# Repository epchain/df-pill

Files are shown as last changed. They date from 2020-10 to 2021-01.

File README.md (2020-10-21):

# df-pill

This project was extracted from another, complex device project which originally
targeted cheap STM32F103C8T6 board known as "bluepill" as main board.
However, it soon became apparent that bluepill has shortcomings with USB
interface, which was meant to be primary communication channel.

**tl;dr** bluepill cannot work with USB while being externally powered.
It is designed to be powered with USB host only.
Some bluepill boards have hardware bugs.

To overcome problems this board was designed.
It has a number of enhancements and was thought to be maximally generic.

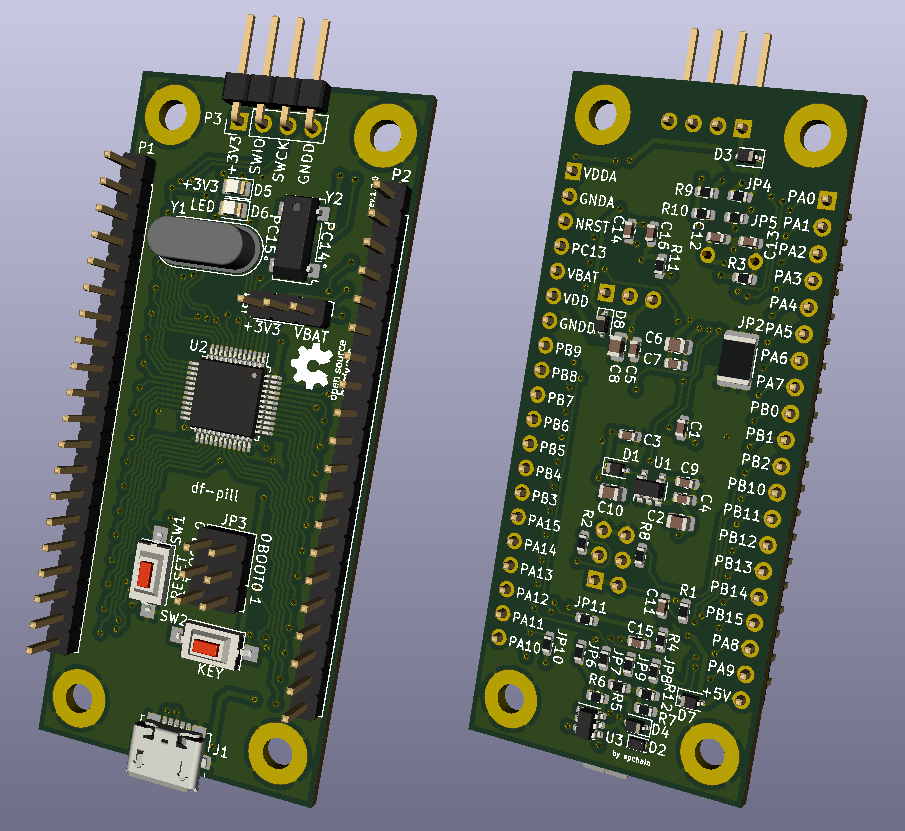
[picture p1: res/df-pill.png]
df-pill


**Enhancements:**

1. Improved USB
  > USB now has optional ESD protection, implements VBUS sense with software
  > and is fully detachable via jumpers.

2. Every pin has external connection
  > NOTE: some pins like PC14, PC15, BOOT0 don't have terminals at the board
  > sides, but still have them at crystal mount points and boot pin headers.

3. Separate analog terminals VDDA and GNDA and separate analog ground
  > NOTE: It is required to provide VDDA and GNDA or simply join them
  > with VDD and GNDD. GNDA and GNDD may be joined on board with jumper.
  > VDD and VDDA may be joined via terminals.

4. Detachable add-ons
  > On-board LEDs and keys can be detached with jumpers.

5. VDD and +5V inputs are protected power inputs.
  > All power supply nets are now protected with Schottky diodes.

The goal of this project is to learn electronics while creating a useful device,
for everyone. So keep in mind that this device isn't designed by professional.

It is assumed that user is able to perform all necessary tasks related to
device creation, which are not covered with project files. User must also
perform all necessary precautions on every such task. See [LICENSE](LICENSE).

This means things like electrical safety, soldering, parts ordering and
PCB manufacturing are out of the scope. As a note, if you think you can
buy bluepill, disassemble it and apply its parts to this board, then
you're right. Bluepill has core parts, but some other uncommon ones need
to be ordered.

# How to use

Install Kicad EDA and open project file: `device/df-pill/df-pill.pro`.
Original project was made with *Kicad EDA 5.1.5-3*

You don't need any library installed, because project is fully autonomous.
It has all symbols, footprints and 3D models in `device/df-pill/lib` dir.

If you like to change anything it is recommended to first add new items
to library and then use them in project to maintain autonomous project
structure.

If you'd like to have multiple boards on a single copper plate
read `device/panelization.md`.

# Versioning

Schematic and and PCB have different, but related version formats.

- Schematic: **X.Y**
- PCB: **X.Y.Z**

Where **X** = major version, **Y** = minor version, **Z** = patch.

Schematic major version increment breaks external interface.
Minor version increment changes components, but external interface
is the same. Any schematic version change breaks PCB layout.

PCB's major and minor versions are from schematic versions.
Patches are PCB modifications/optimizations that are fully
compatible with current schematic.

# References

A number of resources was used in this project.
See [reference.md](reference.md) for list.

# License

This project is licensed under [The Unlicense](LICENSE).
It contains library files from KiCAD EDA library in `device/lib`.
These files are licensed under [KiCAD EDA Libraries License](https://kicad-pcb.org/libraries/license/)

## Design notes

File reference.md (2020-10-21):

# Reference

There you can find a list of all documents used in this project,
given in order from general to more specific.

### USB:

1. [USB 2.0 Specification](https://www.usb.org/sites/default/files/usb_20_20190524.zip)
2. [Mass Storage Class Specification Overview 1.4](https://www.usb.org/sites/default/files/Mass_Storage_Specification_Overview_v1.4_2-19-2010.pdf)
3. [Mass Storage Bulk Only 1.0](https://www.usb.org/sites/default/files/usbmassbulk_10.pdf)
4. [SCSI Primary Commands - 3 (SPC-3)](https://www.t10.org/cgi-bin/ac.pl?t=f&f=spc3r23.pdf)
5. [SCSI Block Commands - 2 (SBC-2)](https://www.t10.org/cgi-bin/ac.pl?t=f&f=sbc2r16.pdf)

### ST:

1. [STM32F103x8-xB Datasheet](https://www.st.com/resource/en/datasheet/stm32f103c8.pdf)
2. [STM32F10xxx Reference manual (RM0008)](https://www.st.com/resource/en/reference_manual/cd00171190.pdf)
4. [Getting started with STM32F10xxx hardware development
 (AN2586)](https://www.st.com/resource/en/application_note/cd00164185.pdf)
5. [Oscillator design guide for STM8AF-AL-S, STM32 MCUs and MPUs (AN2867)](https://www.st.com/resource/en/application_note/cd00221665.pdf)
6. [STM32 GPIO configuration for hardware settings 
and low-power consumption](https://www.st.com/resource/en/application_note/dm00315319.pdf)
7. [USB hardware and PCB guidelines using STM32 MCUs (AN4879)](https://www.st.com/resource/en/application_note/dm00296349.pdf)
8. [Monitoring the VBUS signal for USB self-powered devices (AN1040)](https://www.st.com/resource/en/application_note/cd00004193.pdf)
9. [Management of VBUS sensing for USB device design](https://community.st.com/s/article/FAQ-Management-of-VBUS-sensing-for-USB-device-design)

### Bluepill:

1. [Description from stm32-base.org](https://stm32-base.org/boards/STM32F103C8T6-Blue-Pill)
2. [Schematic](https://developer.mbed.org/media/uploads/martin159/stm32_min_system_dev_board.pdf)
3. [Pinout diagram](http://reblag.dk/wordpress/wp-content/uploads/2016/07/The-Generic-STM32F103-Pinout-Diagram.pdf)

### PCB:

1. [Staying Well Grounded, Hank Zumbahlen](https://www.analog.com/media/en/analog-dialogue/volume-46/number-2/articles/staying_well_grounded.pdf)

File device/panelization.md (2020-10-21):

# Panelization

To reduce manufacturing costs it is possible to create a separate `kicad_pcb`
file and place multiple PCB layouts on a single copper plate.

To do this open KiCad EDA's Pcbnew in standalone mode: launch `pcbnew` binary
instead of opening project with `kicad` binary.

Pcbnew will have `Append Board` option, unavailable in "kicad mode".
You may now append multiple layouts and place them as you like.

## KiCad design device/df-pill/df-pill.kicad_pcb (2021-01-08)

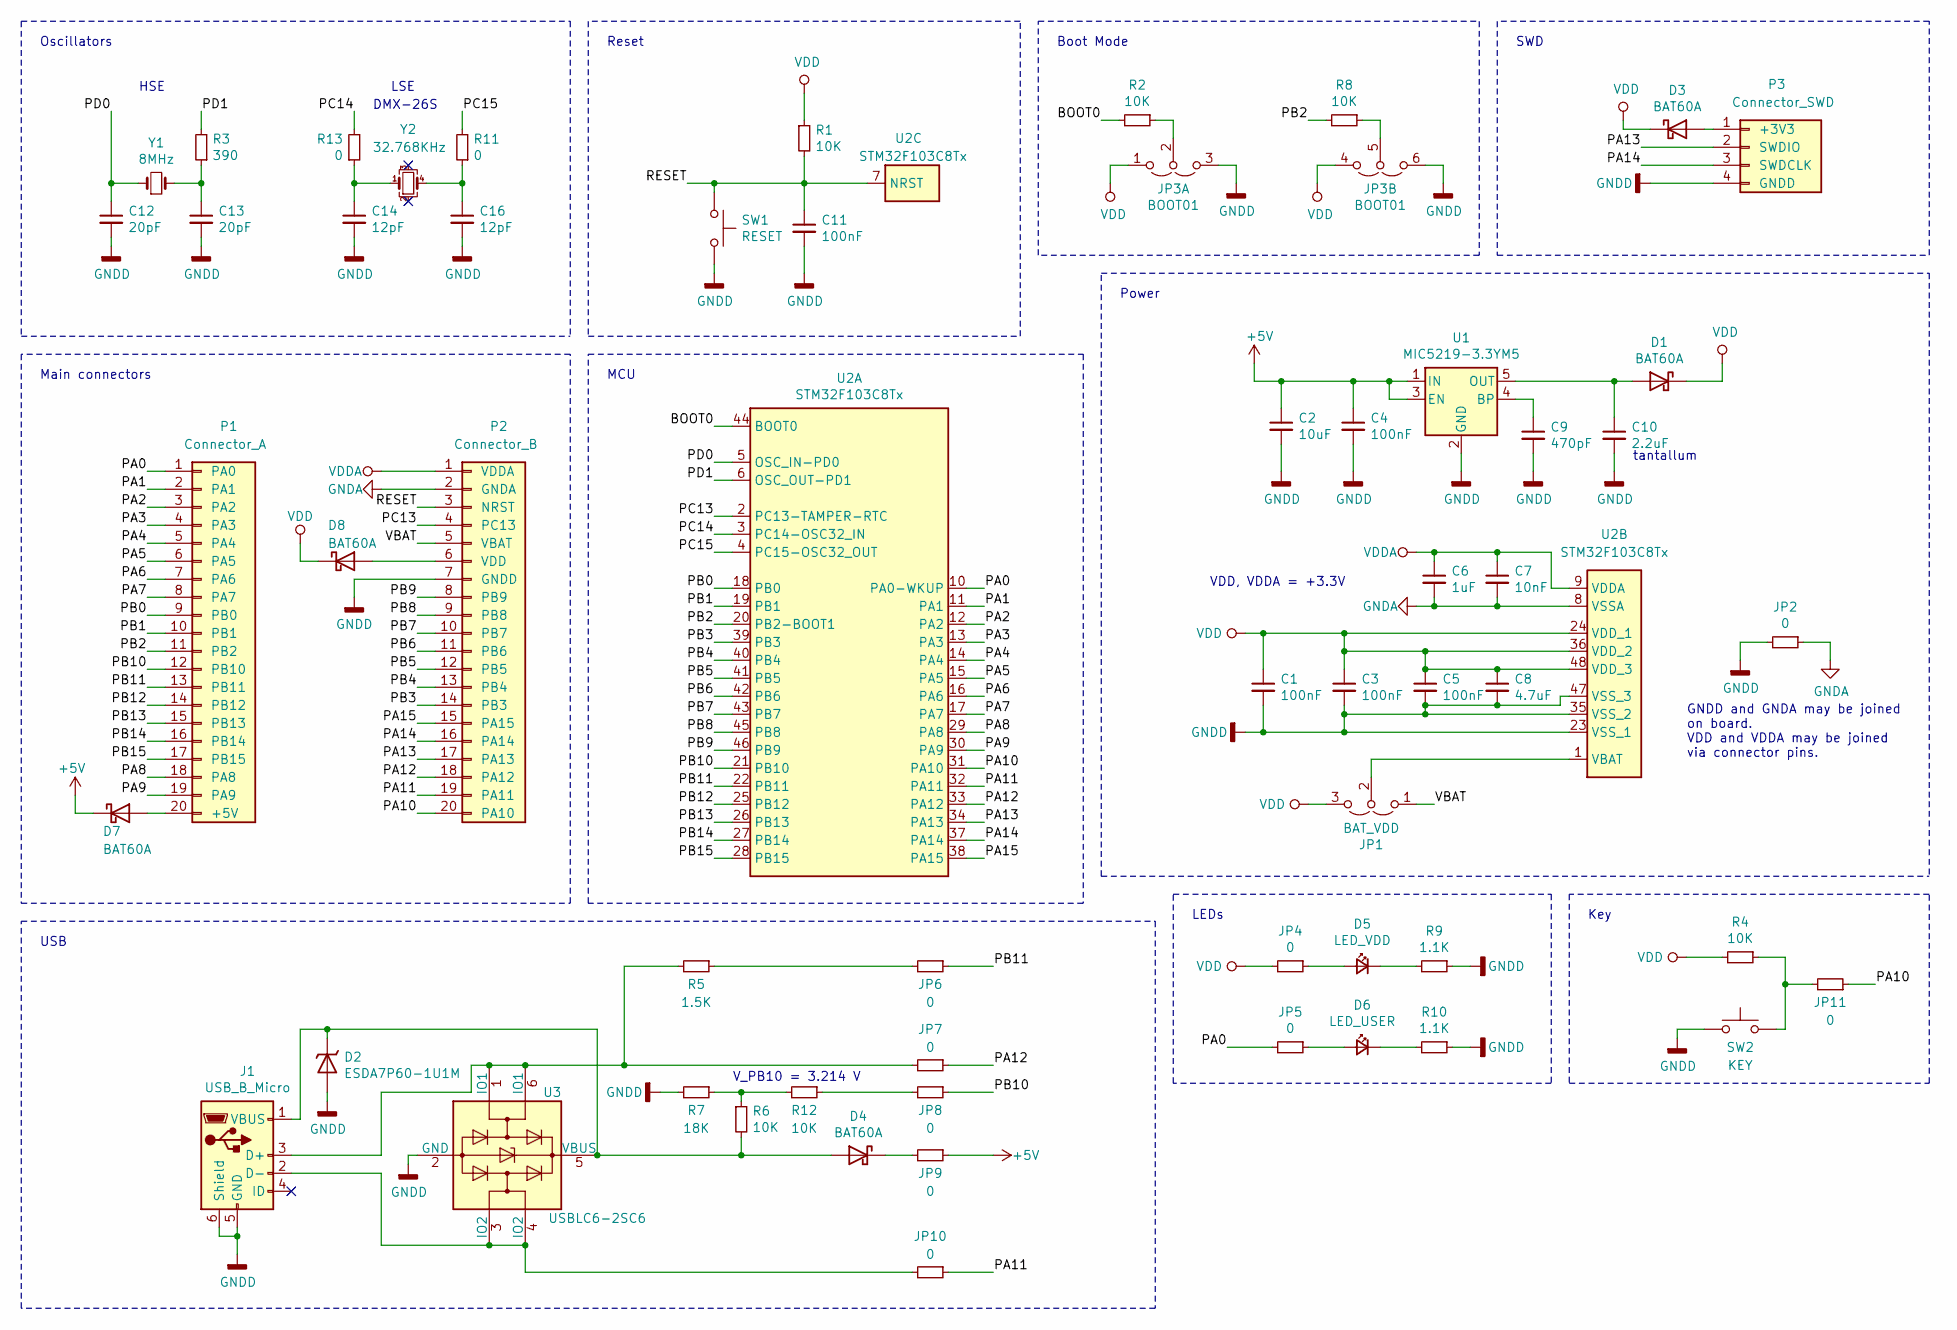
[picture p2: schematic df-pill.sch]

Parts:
C1, C3, C4, C5, C11: 100nF; C_0603_1608Metric
C2: 10uF; C_0805_2012Metric
C6: 1uF; C_0805_2012Metric
C7: 10nF; C_0603_1608Metric
C8: 4.7uF; C_0805_2012Metric
C9: 470pF; C_0603_1608Metric
C10: 2.2uF; C_0805_2012Metric
C12, C13: 20pF; C_0603_1608Metric
C14, C16: 12pF; C_0603_1608Metric
D1, D3, D4, D7, D8: BAT60A; D_SOD-323
D2: ESDA7P60-1U1M; D_1610Metric
D5: LED_VDD; LED_0805_2012Metric
D6: LED_USER; LED_0805_2012Metric
J1: USB_B_Micro; USB_Micro-B_Molex_47346-0001
JP1: BAT_VDD; PinHeader_1x03_P2.54mm_Vertical
JP2: 0; R_1812_4532Metric
JP3: BOOT01; PinHeader_2x03_P2.54mm_Vertical
JP4, JP5, JP6, JP7, JP8, JP9, JP10, JP11: 0; R_0603_1608Metric
P1: Connector_A; PinHeader_1x20_P2.54mm_Vertical
P2: Connector_B; PinHeader_1x20_P2.54mm_Vertical
P3: Connector_SWD; PinHeader_1x04_P2.54mm_Vertical
R1, R2, R4, R6, R8, R12: 10K; R_0603_1608Metric
R3: 390; R_0603_1608Metric
R5: 1.5K; R_0603_1608Metric
R7: 18K; R_0603_1608Metric
R9, R10: 1.1K; R_0603_1608Metric
R11, R13: 0; R_0603_1608Metric
SW1: RESET; SW_SPST_CK_RS282G05A3
SW2: KEY; SW_SPST_CK_RS282G05A3
U1: MIC5219-3.3YM5; SOT-23-5
U2: STM32F103C8Tx; LQFP-48_7x7mm_P0.5mm
U3: USBLC6-2SC6; SOT-23-6
Y1: 8MHz; Crystal_HC49-4H_Vertical
Y2: 32.768KHz; Crystal_SMD_Abracon_ABS25-4Pin_8.0x3.8mm

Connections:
+5V: C2.1, C4.1, D7.1 (K), JP9.1, U1.1 (IN), U1.3 (EN)
/BOOT0: R2.2, U2.44 (BOOT0)
/PA0: JP5.2, P1.1 (PA0), U2.10 (PA0-WKUP)
/PA1: P1.2 (PA1), U2.11 (PA1)
/PA2: P1.3 (PA2), U2.12 (PA2)
/PA3: P1.4 (PA3), U2.13 (PA3)
/PA4: P1.5 (PA4), U2.14 (PA4)
/PA5: P1.6 (PA5), U2.15 (PA5)
/PA6: P1.7 (PA6), U2.16 (PA6)
/PA7: P1.8 (PA7), U2.17 (PA7)
/PA8: P1.18 (PA8), U2.29 (PA8)
/PA9: P1.19 (PA9), U2.30 (PA9)
/PA10: JP11.1, P2.20 (PA10), U2.31 (PA10)
/PA11: JP10.1, P2.19 (PA11), U2.32 (PA11)
/PA12: JP7.1, P2.18 (PA12), U2.33 (PA12)
/PA13: P2.17 (PA13), P3.2 (SWDIO), U2.34 (PA13)
/PA14: P2.16 (PA14), P3.3 (SWDCLK), U2.37 (PA14)
/PA15: P2.15 (PA15), U2.38 (PA15)
/PB0: P1.9 (PB0), U2.18 (PB0)
/PB1: P1.10 (PB1), U2.19 (PB1)
/PB2: P1.11 (PB2), R8.2, U2.20 (PB2-BOOT1)
/PB3: P2.14 (PB3), U2.39 (PB3)
/PB4: P2.13 (PB4), U2.40 (PB4)
/PB5: P2.12 (PB5), U2.41 (PB5)
/PB6: P2.11 (PB6), U2.42 (PB6)
/PB7: P2.10 (PB7), U2.43 (PB7)
/PB8: P2.9 (PB8), U2.45 (PB8)
/PB9: P2.8 (PB9), U2.46 (PB9)
/PB10: JP8.1, P1.12 (PB10), U2.21 (PB10)
/PB11: JP6.1, P1.13 (PB11), U2.22 (PB11)
/PB12: P1.14 (PB12), U2.25 (PB12)
/PB13: P1.15 (PB13), U2.26 (PB13)
/PB14: P1.16 (PB14), U2.27 (PB14)
/PB15: P1.17 (PB15), U2.28 (PB15)
/PC13: P2.4 (PC13), U2.2 (PC13-TAMPER-RTC)
/PC14: R13.2, U2.3 (PC14-OSC32_IN)
/PC15: R11.2, U2.4 (PC15-OSC32_OUT)
/PD0: C12.1, U2.5 (OSC_IN-PD0), Y1.1
/PD1: R3.2, U2.6 (OSC_OUT-PD1)
/RESET: C11.1, P2.3 (NRST), R1.2, SW1.1, U2.7 (NRST)
/VBAT: JP1.1 (A), P2.5 (VBAT)
GNDA: C6.2, C7.2, JP2.1, P2.2 (GNDA), U2.8 (VSSA)
GNDD: C1.2, C2.2, C3.2, C4.2, C5.2, C8.2, C9.2, C10.2, C11.2, C12.2, C13.2, C14.2, C16.2, D2.2 (A2), J1.5 (GND), J1.6 (Shield), JP2.2, JP3.3 (B), JP3.6 (B), P2.7 (GNDD), P3.4 (GNDD), R7.2, R9.1, R10.1, SW1.2, SW2.1, U1.2 (GND), U2.23 (VSS_1), U2.35 (VSS_2), U2.47 (VSS_3), U3.2 (GND)
unnamed: C9.1, U1.4 (BP)
unnamed: C10.1, D1.2 (A), U1.5 (OUT)
unnamed: C13.1, R3.1, Y1.2
unnamed: C14.1, R13.1, Y2.1
unnamed: C16.1, R11.1, Y2.4
unnamed: D2.1 (A1), D4.2 (A), J1.1 (VBUS), R6.2, U3.5 (VBUS)
unnamed: D3.2 (A), P3.1 (+3V3)
unnamed: D4.1 (K), JP9.2
unnamed: D5.1 (K), R9.2
unnamed: D5.2 (A), JP4.1
unnamed: D6.1 (K), R10.2
unnamed: D6.2 (A), JP5.1
unnamed: D7.2 (A), P1.20 (+5V)
unnamed: D8.2 (A), P2.6 (VDD)
unnamed: J1.2 (D-), JP10.2, U3.3 (IO2), U3.4 (IO2)
unnamed: J1.3 (D+), JP7.2, R5.2, U3.1 (IO1), U3.6 (IO1)
unnamed: JP1.2 (C), U2.1 (VBAT)
unnamed: JP3.2 (C), R2.1
unnamed: JP3.5 (C), R8.1
unnamed: JP6.2, R5.1
unnamed: JP8.2, R12.1
unnamed: JP11.2, R4.1, SW2.2
unnamed: R6.1, R7.1, R12.2
VDD: C1.1, C3.1, C5.1, C8.1, D1.1 (K), D3.1 (K), D8.1 (K), JP1.3 (B), JP3.1 (A), JP3.4 (A), JP4.2, R1.1, R4.2, U2.24 (VDD_1), U2.36 (VDD_2), U2.48 (VDD_3)
VDDA: C6.1, C7.1, P2.1 (VDDA), U2.9 (VDDA)

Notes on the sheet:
Power
GNDD and GNDA may be joined on board. VDD and VDDA may be joined via connector pins.
Oscillators
Boot Mode
HSE
LSE
DMX-26S
Reset
VDD, VDDA = +3.3V
MCU
USB
LEDs
tantallum
SWD
Main connectors
Key
V_PB10 = 3.214 V

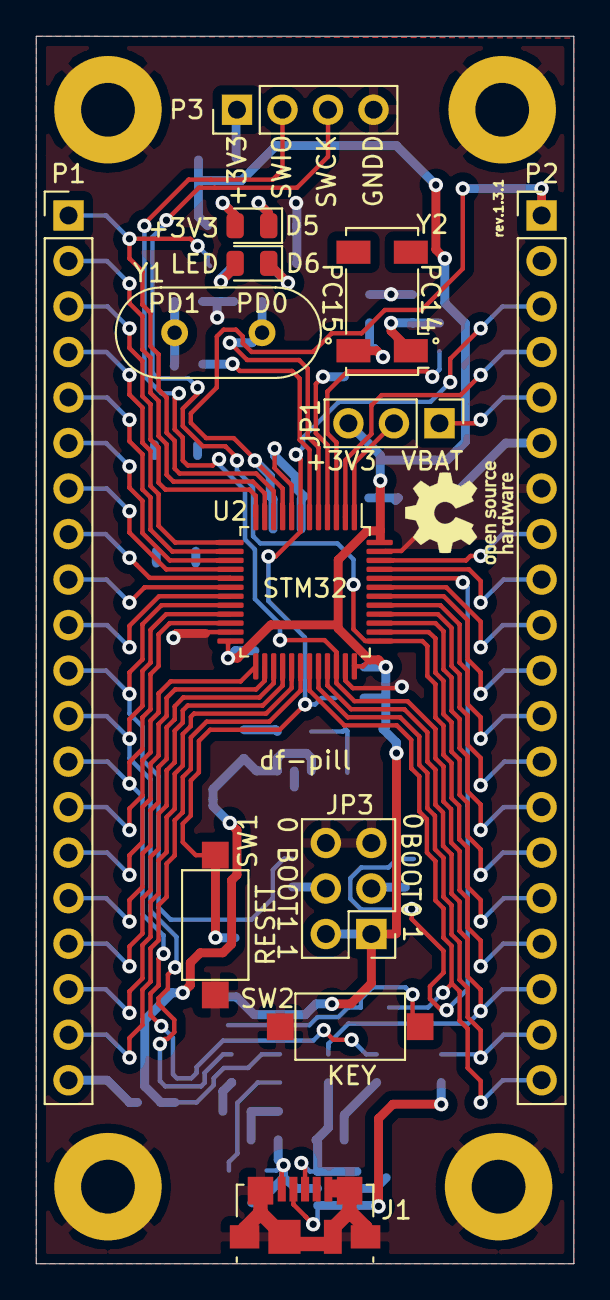
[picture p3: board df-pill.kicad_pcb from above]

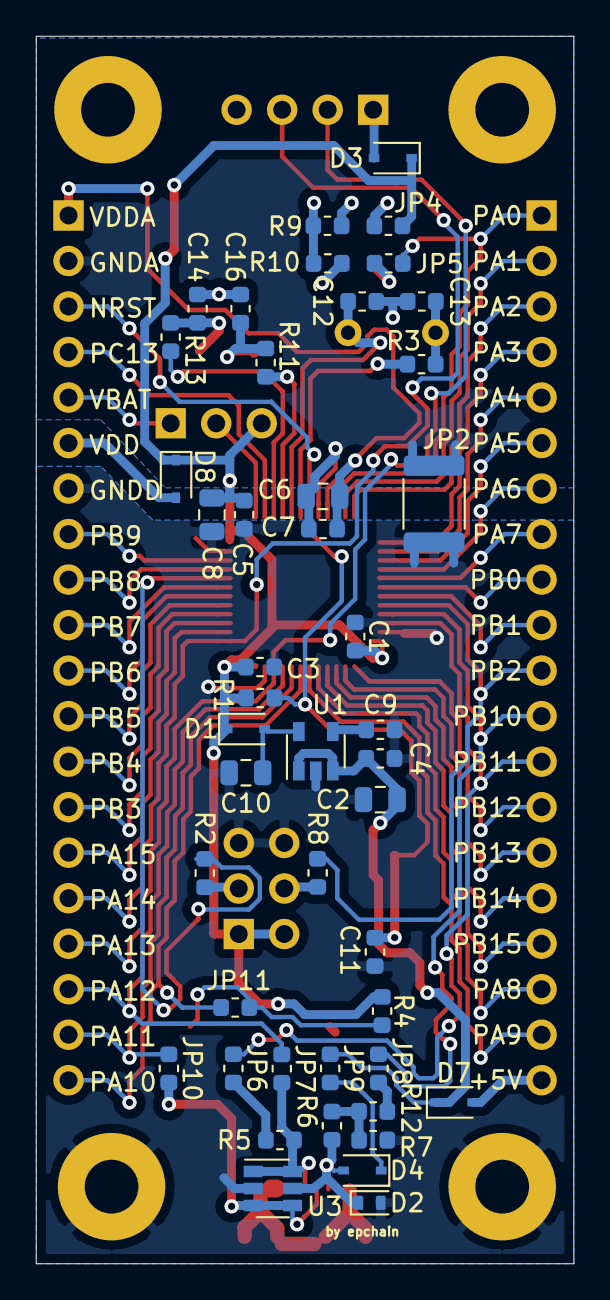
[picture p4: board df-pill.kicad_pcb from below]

Board: 2 copper layers, 30.0 x 68.5 mm, 58 parts (45 on the bottom side), 68 nets.

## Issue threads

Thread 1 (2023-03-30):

JP1

domiiis, 2023-03-30:
Hello, I was wondering, what for is that header JP1 (VDD, BAT_VDD and VBAT.

epchain, 2023-03-31:
Hello. This is the convenience header that allows you to switch VBAT power supply source to VDD or to battery connected to VBAT pin, or disconnect VBAT from anything. When no external battery is used ST recommends to connect VBAT to VDD.

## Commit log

2020-10-21 Public release
    [df-pill.kicad_pcb, df-pill.sch]
2020-12-20 rev.1.3.0
    Fix schematic symbols and footprints to point to local library
    Fix D4 position
    Add R13 as a jumper for separating PC14 from LSE
    Change Key from pull-down to pull-up
    Remove C15 in favor of software debouncing for Key
    [df-pill.kicad_pcb, df-pill.sch]
2021-01-08 Fix silk layer for D1 and R1
    [df-pill.kicad_pcb]
